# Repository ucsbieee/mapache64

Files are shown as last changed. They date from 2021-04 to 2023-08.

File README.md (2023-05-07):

# Mapache 64

* Repository: [github.com/ucsbieee/mapache64](https://github.com/ucsbieee/mapache64)
* Website: [mapache64.ucsbieee.org](https://mapache64.ucsbieee.org)
* Discord Server: [discord.ucsbieee.org](http://discord.ucsbieee.org)

## Description

Mapache 64 is is a custom video game console based around the 6502 microprocessor. This console uses a custom graphics processing unit (GPU) written in SystemVerilog and runs on a [Cmod A7-35T](https://digilent.com/reference/programmable-logic/cmod-a7/). The firmware and games are programmed using C, and can be compiled with a custom linker script and [`cc65`](https://cc65.github.io), an open-source C to 6502 assembly compiler. This project was developed by [UC Santa Barbara's IEEE chapter](https://ucsbieee.org/), led by [Ethan Sifferman](https://github.com/sifferman).

Video screen:

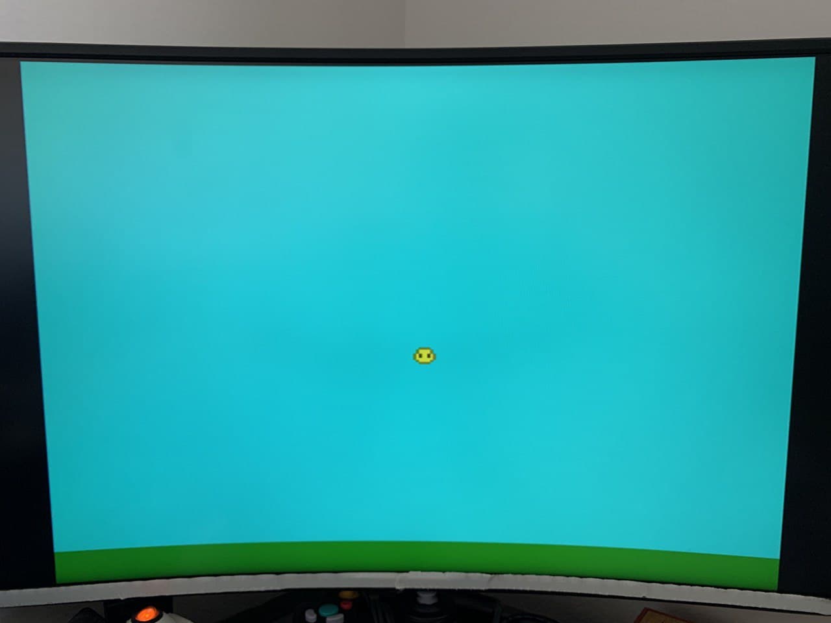
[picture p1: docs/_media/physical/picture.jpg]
Video Screen


Breadboard circuit:

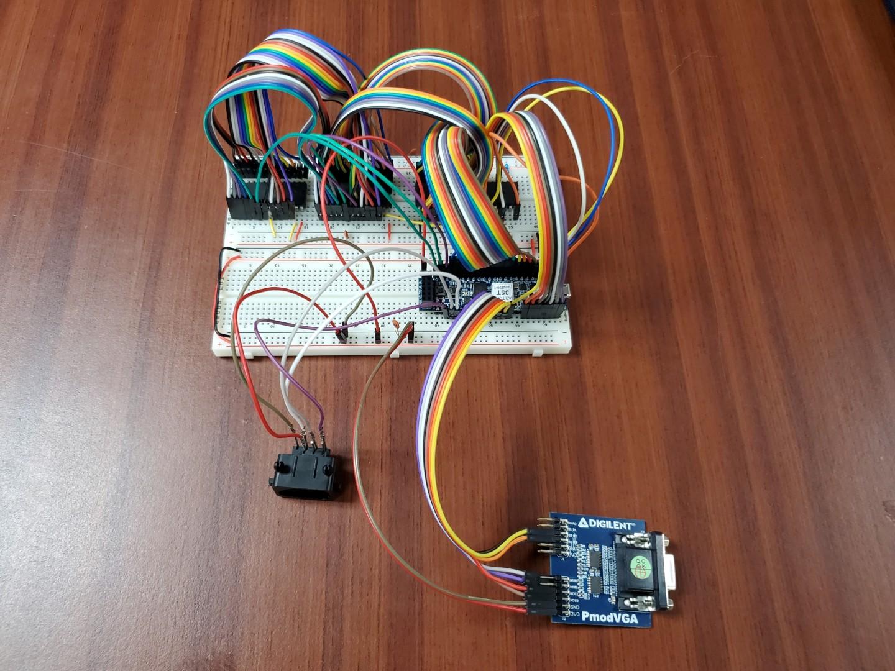
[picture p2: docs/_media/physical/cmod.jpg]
Breadboard Circuit


## References

### Games List

* [Asteroids](https://github.com/sifferman/m64-a2teroids) (2-player asteroids)
* [Flappy Bird](https://github.com/mfletcher2/mapache64-flappybird)
* [Snake](https://github.com/GDW1/m64-snake)
* [Pong](https://github.com/GDW1/m64-pong)
* [Tetris](https://github.com/ucsbieee/m64-tetris)
* [Frogger](https://github.com/ucsbieee/m64-frogger)

### Guides

* [Ben Eater 6502 Computer Video Series](https://www.youtube.com/watch?v=LnzuMJLZRdU&list=PLowKtXNTBypFbtuVMUVXNR0z1mu7dp7eH)
* [Ben Eater VGA](https://youtu.be/uqY3FMuMuRo)
* [NES PPU Explanation](https://www.youtube.com/watch?v=-THeUXqR3zY&list=PLrOv9FMX8xJHqMvSGB_9G9nZZ_4IgteYf&index=5)

### Datasheets

* [W65C02S](https://westerndesigncenter.com/wdc/documentation/w65c02s.pdf) Microprocessor
* [AT28C256](http://ww1.microchip.com/downloads/en/DeviceDoc/doc0006.pdf) 32kB EEPROM
* [AS6C62256](https://www.alliancememory.com/wp-content/uploads/pdf/AS6C62256.pdf) 32kB SRAM
* [Cmod A7](https://digilent.com/reference/programmable-logic/cmod-a7/reference-manual) FPGA board
* [VESA, 640x480 @ 60 Hz Video Timing](http://www.tinyvga.com/vga-timing/640x480@60Hz) guide

---

### Credits

#### RTL Development

* Ethan Sifferman ([github](https://github.com/sifferman))
* *Jon Balkind (consultant)* ([github](https://github.com/jbalkind))

#### PCB Development

* Ethan Sifferman ([github](https://github.com/sifferman))
* Matthew Tom ([github](https://github.com/Matthew-Tom))
* Kogan Sam ([github](https://github.com/02ks))
* Neil Balch ([github](https://github.com/neilbalch))
* *Daniel Van Dalsem (consultant)* ([github](https://github.com/aWZHY0yQH81uOYvH))

#### Firmware Development

* Ethan Sifferman ([github](https://github.com/sifferman))
* Neil Balch ([github](https://github.com/neilbalch))

#### Game Development

* Ethan Sifferman ([github](https://github.com/sifferman))
* Max Fletcher ([github](https://github.com/mfletcher2))
* Guy Wilks ([github](https://github.com/GDW1))

#### Website Development

* Ethan Sifferman ([github](https://github.com/sifferman))
* Neil Balch ([github](https://github.com/neilbalch))
* Max Fletcher ([github](https://github.com/mfletcher2))
* Xingbu Qin ([github](https://github.com/watercannons))
* Nicolas Guglielmin ([github](https://github.com/nicg6645))

---

## Name Explanation

* Mapache is the unofficial mascot of UC Santa Barbara ([source](https://www.change.org/p/the-mascot-we-deserve-change-the-ucsb-mascot-to-a-mapache))
* Mapache 64 has 64kiB of address space

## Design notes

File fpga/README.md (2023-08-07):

<!-- fpga/README.md -->

# FPGA

Repository: <https://github.com/ucsbieee/mapache64/tree/main/fpga/>

## RTL

This is the RTL for Mapache 64. It consists of the following modules:

* Address Bus
  * Sets chip enable signals according to the current cpu address.
* [Controller Interface](https://github.com/sifferman/nes_controller_interface)
  * Reads the controller values. (SIPO)
* Firmware ROM
  * The firmware and 65c02 vectors are stored in BRAM.
* GPU
  * Implementation of this description: [GPU](https://mapache64.ucsbieee.org/guides/gpu/).

## Required tools

* [FuseSoC](https://github.com/olofk/fusesoc)
* [OSS CAD Suite](https://github.com/YosysHQ/oss-cad-suite-build)
* [Vivado ML Enterprise](https://www.xilinx.com/products/design-tools/vivado.html)
* [Cmod A7-35T](https://store.digilentinc.com/cmod-a7-breadboardable-artix-7-fpga-module/)

## Usage

```bash
# setup
git submodule update --init --recursive
cd fpga
./rom/get_firmware.sh
./rom/get_font.sh
fusesoc library add ucsbieee_mapache64_top . --sync-type=local
fusesoc library add nes_controller_interface https://github.com/sifferman/nes_controller_interface --sync-type=git

# Lint with Verilator
fusesoc run --target lint --no-export ucsbieee:mapache64:top
# Simulate with Icarus
fusesoc run --target sim --tool icarus ucsbieee:mapache64:top
# Simulate with Verilator
fusesoc run --target sim --tool verilator ucsbieee:mapache64:top
# Synthesize for the Cmod-A7
fusesoc run --target cmod_a7 ucsbieee:mapache64:top
# Verify the GPU
fusesoc run --target gpu_verify ucsbieee:mapache64:top
```

Cmod-A7 SPI Flash: `mx25l3273f`

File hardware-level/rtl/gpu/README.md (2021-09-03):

<!-- hardware-level/rtl/gpu-reduced/README.md -->

# GPU

Repository: <https://github.com/ucsbieee/arcade/tree/main/hardware-level/rtl/gpu>

## About

This is a draft of the GPU described in [GPU](https://arcade.ucsbieee.org/guides/gpu/).

## Required tools

* [FuseSoC](https://github.com/olofk/fusesoc) ([installation](https://fusesoc.readthedocs.io/en/stable/user/installation.html))
* [Icarus Verilog](http://iverilog.icarus.com/) ([installation](https://iverilog.fandom.com/wiki/Installation_Guide))
* [Vivado ML Enterprise](https://www.xilinx.com/products/design-tools/vivado.html) ([installation](https://www.xilinx.com/support/download.html))
* [Nexys A7-100T](https://store.digilentinc.com/nexys-a7-fpga-trainer-board-recommended-for-ece-curriculum/)
* [CMOD A7-35T](https://store.digilentinc.com/cmod-a7-breadboardable-artix-7-fpga-module/)

## Usage

To simulate in Icarus Verilog:

```bash
./scripts/sim.sh
```

To synthesize for Nexys A7-100T:

```bash
./scripts/nexys_a7.sh
```

To synthesize for CMOD A7-35T:

```bash
./scripts/cmod_a7.sh
```

Libraries Used:

* [E4tHam/find_first_set](https://github.com/E4tHam/find_first_set)

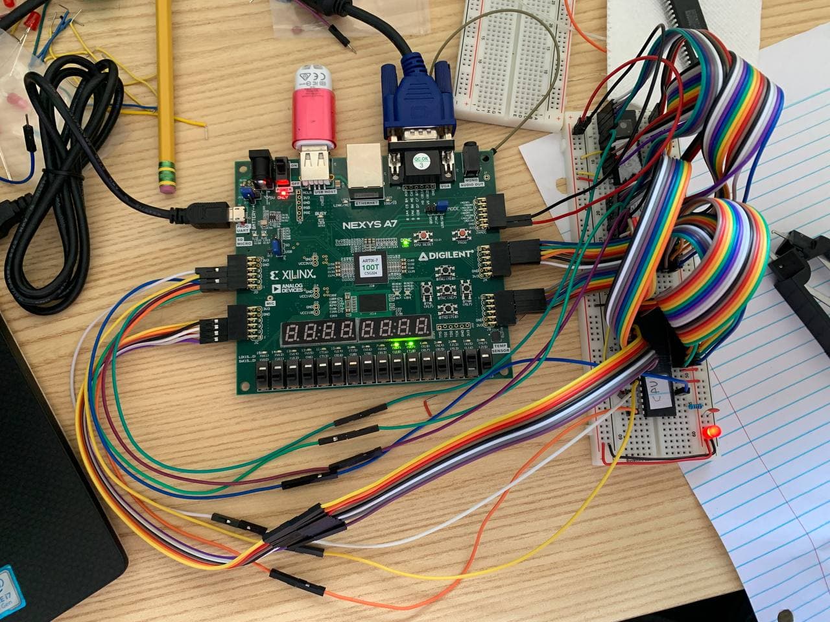
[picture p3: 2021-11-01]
docs/_media/physical/nexys_a7.jpg

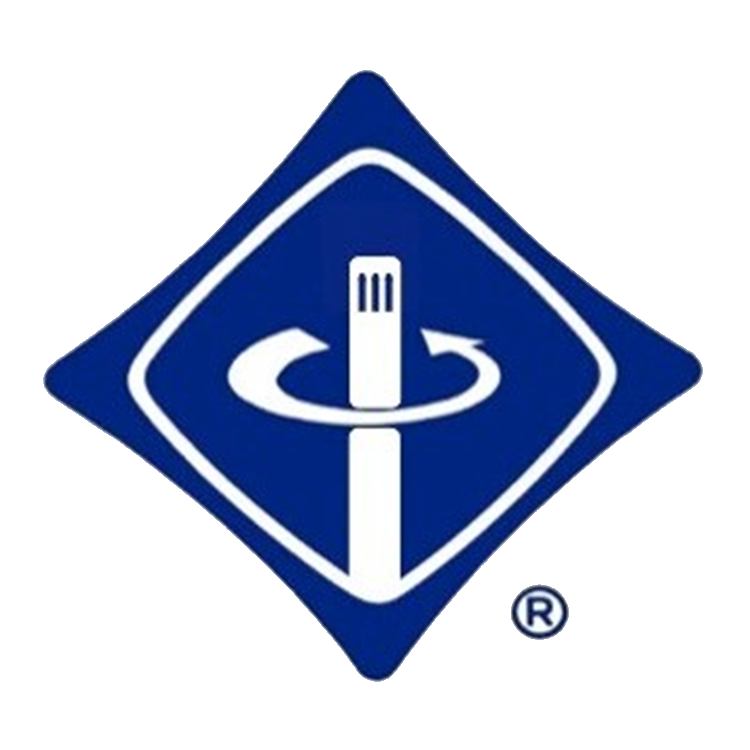
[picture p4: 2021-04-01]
docs/_media/UCSB-IEEE.png

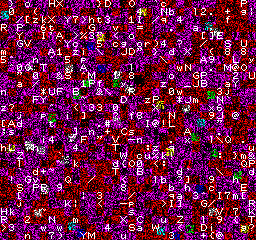
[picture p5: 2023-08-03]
fpga/dv/gpu/gold_images/random_red_magenta.png

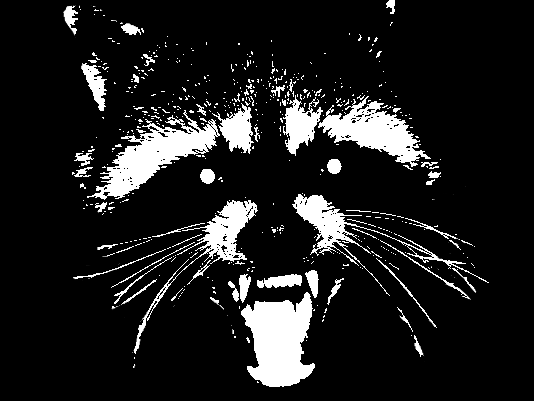
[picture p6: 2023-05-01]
PCB/mapache.png

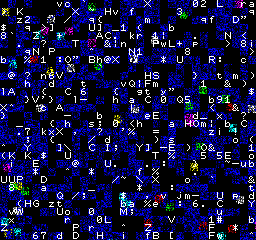
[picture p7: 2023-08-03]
fpga/dv/gpu/gold_images/random_blue_black.png

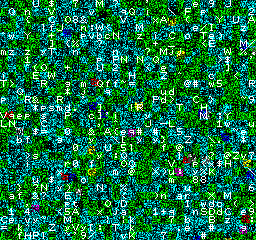
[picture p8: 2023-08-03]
fpga/dv/gpu/gold_images/random_green_cyan.png

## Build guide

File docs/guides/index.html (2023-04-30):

back

# Guides

- GPU Explanation
- Creating a Game (https://github.com/ucsbieee/mapache64/tree/main/firmware#creating-a-game)
- Emulating a Game in JavaScript

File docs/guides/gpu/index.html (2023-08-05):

back

# GPU

# Table of Contents

- Overview
- Pattern Memory
- Nametable
- Object Memory
- Text Table
- Video Timing

# Overview

All the GPU does is display to the screen based off what is in the VRAM. Therefore, to display to the screen, you must fill the VRAM accordingly. If you are using Mapache 64's custom linker script, you can use the API described in vram.h (https://github.com/ucsbieee/mapache64/blob/main/firmware/headers/vram.h).

There are 4 parts of the VRAM: Pattern Memory, Nametable, Object Memory, and Text Table.

- The pattern memory (PMF and PMB) stores pixel data for 32 foreground sprites and 32 background sprites.
- The Nametable (NTBL) stores the arrangement of 32×30 background tiles on the screen.
- The Object Memory (OBM) stores the arrangement of 64 foreground sprites.
- The Text Table (TXBL) stores the arrangement of 32×30 characters on the screen.

If you’ve never worked with sprites and tiles, I recommend learning how NES sprites are stored and assembled into metasprites before proceeding:

Ethan’s Image Binary Data Lecture (https://ieee.sifferman.dev/W21-BinHacking/Lecture/21-01-30/#Sprites)

Note: the GPU in this project took heavy inspiration from the NES’s PPU:

One Lone Coder’s NES PPU Explanation (https://www.youtube.com/watch?v=-THeUXqR3zY&list=PLrOv9FMX8xJHqMvSGB_9G9nZZ_4IgteYf&index=5)

# Pattern Memory

Pattern Memory stores collections of 8px×8px sprites. Each pixel is stored with 2 bits, and a group of 4 pixels is stored as 1 byte. Each sprite is 16 bytes total.

Pixel Data

- 11 is white
- 10 is light gray
- 01 is dark gray
- 00 is transparent for PMF, black for PMB

Note: pixel data is separate from color data. A color filter can be applied over a sprite by the Nametable or Object Memory.

Pixel Data

- Pattern Memory Foreground (PMF) only holds 32 foreground sprites, and is addressable with 5 bits.
- Pattern Memory Background (PMB) only holds 32 background sprites, and is addressable with 5 bits.

Observe the layout of the Pattern Memory:

Pattern Memory Diagram

This is an example of how sprites are stored in PMF.

# Nametable

The Nametable is a 32×30 array of tiles that represent the entire 256px×240px screen. Each tile must choose 1 sprite from PMB to display. Each tile can be flipped horizontally and flipped vertically. This allows for reuse of sprites.

The Nametable also stores 2 global colors. Each tile must select one of the two colors. You can look at the VRAM Randomizer example to see this in action.

Nametable Diagram

# Object Memory

The Object Memory is used to identify the location of the sprites on the screen.

Each object has an X and Y position, a sprite address, an H-Flip and V-Flip modifier, and a color. If two objects overlap, whichever object appears first in OBM will be on top.

Object Memory Diagram

# Text Table

The Text Table (TXBL) can be used to write text over the screen. The TXBL is similar to the NTBL, except the TXBL's tiles appear in front of foreground objects and uses read-only character pattern memory (PMC) instead of custom sprites from the PMB.

There are 128 characters in the font. Each character can be accessed by using the lower 7 bits of the character data in the TXBL. The font uses ASCII for all printable characters.

PMC Font (https://github.com/ucsbieee/mapache64/blob/main/txbl_font/font.png)

If the character data's color select is 0, the character is printed black. If the character data's color select is 1, the character is printed white.

Text Table Diagram

# Video Timing

The GPU will follow the VESA 640×480 @ 60 Hz protocol (http://www.tinyvga.com/vga-timing/640x480@60Hz). Observe this timing diagram:

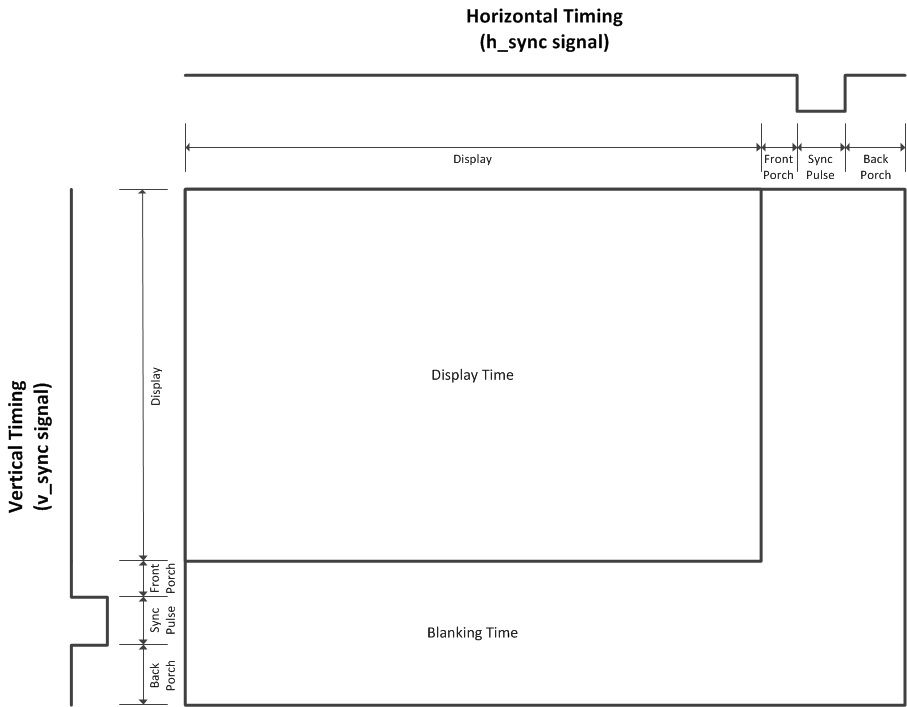
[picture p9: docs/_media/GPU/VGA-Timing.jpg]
VGA Timing Diagram
 (https://www.digikey.com/eewiki/pages/viewpage.action?pageId=15925278)

The GPU updates each pixel row by row. After drawing a row, it waits for a horizontal blanking period. After finishing the entire frame, it waits for a vertical blanking period.

If you want more information about video timings, watch this:

Ben Eater Graphics Card Video (https://youtu.be/l7rce6IQDWs)

## Interrupts

The CPU must only touch the VRAM while inside the fill_vram subroutine. This ensures that the CPU and the GPU are not trying to access the VRAM at the same time. Every time the GPU needs to use the VRAM, it sends an interrupt to the CPU. If the CPU is in fill_vram, it will pause. Once the GPU no longer needs the VRAM, it will send another interrupt to the CPU so that the CPU knows when to continue. Observe this code:

interrupts.s (https://raw.githubusercontent.com/ucsbieee/mapache64/main/firmware/backend_src/crt0.s)

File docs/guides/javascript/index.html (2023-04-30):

back

# JavaScript

# Table of Contents

- Game Code Structure
- Fixed Point
- Running JavaScript

# JavaScript Code Structure

JavaScript can be used to write emulations of games. This may be helpful since the C development tools are more difficult. This guide will help you get started.

## HTML

Your HTML file must include the scripts firmware.js, font.js machine.js, game.js, and player.js in that order; and it must include div#Game in body. Example code: game-demo/index.html (https://github.com/ucsbieee/mapache64/blob/main/docs/examples/game-demo/index.html).

## JavaScript

Your JavaScript file must have the functions reset(), do_logic(), and fill_vram(). Example code: game-demo.js (https://github.com/ucsbieee/mapache64/blob/main/docs/_emulator/examples/game-demo.js).

- reset(): run once at the beginning of the code
- do_logic(): run 60 times a second. Put as much game logic here as you can. However, do not touch the VRAM
- fill_vram(): run after do_logic(), once in the vertical blanking area. Here, you can touch the VRAM

# Floating Point vs. Fixed Point

The 65C02 does not have any built-in floating-point functionality. Therefore, we will instead use fixed-point numbers for continuous values.

Fixed Point Numbers (https://en.wikipedia.org/wiki/Q_(number_format))

We have a Q9_6 implementation in firmware.js (https://github.com/ucsbieee/mapache64/blob/main/docs/_emulator/firmware.js). You can see its usage in game-demo.js (https://github.com/ucsbieee/mapache64/blob/main/docs/_emulator/examples/game-demo.js).

Never use floating point numbers! If you need non-integers, use Q9_6.

# Running JavaScript

JavaScript is run by opening an html file in a browser. The easiest way to open html files is through VSCode and Live Server. Install it here:

Live Server VS Code (https://marketplace.visualstudio.com/items?itemName=ritwickdey.LiveServer)

To include a JavaScript file in an html file, you need to add a script:src tag to the head section, and provide the source path/link. Observe this code block:

Note: Append defer to all script elements.

## CDNs

CDN stands for content delivery network. We use a CDN to retrieve JavaScript files from https links instead of paths. A JS Deliver (https://www.jsdelivr.com/github) CDN link has this structure: https://cdn.jsdelivr.net/gh/<org/user name>/<repository>@main/<path>. Any changes to files that are pointed to by a CDN link will take ~2 hours to show up.

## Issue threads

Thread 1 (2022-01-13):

New Functionality: FPS Limiter

E4tHam, 2022-01-13:
There should be support for FPS limiting by integer division (60, 30, 20, 15, 12...).

## Proposed Solution

1. Add a clock to the FPGA that outputs "time since reset" to a 4 byte register in ($7000...$7fff).
2. In [crt0.s](https://github.com/ucsbieee/mapache64/blob/edd41f/assembly-level/src/backend_src/crt0.s), instead of immediately jumping into the interrupt handler on [L82](https://github.com/ucsbieee/mapache64/blob/edd41f/assembly-level/src/backend_src/crt0.s#L82), there should be a check for if enough time has passed.

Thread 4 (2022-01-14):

New Functionality: Firmware Error Code

E4tHam, 2022-01-14:
Currently, if the fpga firmware header does not match the rom firmware header, the M64 will print `'F'` in `TXBL[0][0]`. This is implemented in [`handle_bad_firmware`](https://github.com/ucsbieee/mapache64/blob/e23d07/assembly-level/src/backend_src/verify_firmware.s#L41-L47). Ideally, there should be a more detailed error code.

## Proposed Solution

If the firmwares don't match, we should print both the fpga firmware header and rom firmware header. Note that if the null terminator is not found in a header, the header is assumed to be 256 bytes.

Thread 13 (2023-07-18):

Documentation: Pattern Memory Diagram Should be fixed

sifferman, 2023-07-18:
The provided diagram that demonstrates pattern memory should be corrected. Currently, a diagram representing what the NES does is provided:
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

A better image to use would probably be to use the picture from the "game demo": https://github.com/ucsbieee/mapache64/blob/3403696af758ce0635e767c9e549b5889565007a/firmware/demos/game/patterns.c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

sifferman, 2023-08-04:
Fixed by ed003a65cb620b7cf53a0c9cba3a19346fb04f44

Closed 2023-08-04.

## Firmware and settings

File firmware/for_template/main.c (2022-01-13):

// ==================== main.c ==================== //
// Follow this file template to implement your game //
// ================================================ //

#define SIM 1 // change value depending if running simulation or not

// ================================ //
#pragma code-name ("CODE")
#pragma bss-name ("BSS")

#include <int.h>
#include <vram.h>
#include <stop.h>
#include <Q9_6.h>
#include <mapache64_zero_page.h>
#include <controller.h>
#include <screen.h>


// run once on startup
void reset(void) { }

// run 60 times a second
void do_logic(void) { }

// run after do_logic and once gpu is idle
void fill_vram(void) { }

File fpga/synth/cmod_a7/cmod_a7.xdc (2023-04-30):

## This file is a general .xdc for the CmodA7 rev. B
## https://github.com/Digilent/digilent-xdc/blob/master/Cmod-A7-Master.xdc
## To use it in a project:
## - uncomment the lines corresponding to used pins
## - rename the used ports (in each line, after get_ports) according to the top level signal names in the project

## 12 MHz Clock Signal
set_property -dict { PACKAGE_PIN L17   IOSTANDARD LVCMOS33 } [get_ports { sysclk }]; #IO_L12P_T1_MRCC_14 Sch=gclk

## LEDs
set_property -dict { PACKAGE_PIN A17   IOSTANDARD LVCMOS33 } [get_ports { led[0] }]; #IO_L12N_T1_MRCC_16 Sch=led[1]
set_property -dict { PACKAGE_PIN C16   IOSTANDARD LVCMOS33 } [get_ports { led[1] }]; #IO_L13P_T2_MRCC_16 Sch=led[2]

## RGB LED
set_property -dict { PACKAGE_PIN C17   IOSTANDARD LVCMOS33 } [get_ports { led_rgbB[2] }]; #IO_L14P_T2_SRCC_16 Sch=led0_r
set_property -dict { PACKAGE_PIN B16   IOSTANDARD LVCMOS33 } [get_ports { led_rgbB[1] }]; #IO_L13N_T2_MRCC_16 Sch=led0_g
set_property -dict { PACKAGE_PIN B17   IOSTANDARD LVCMOS33 } [get_ports { led_rgbB[0] }]; #IO_L14N_T2_SRCC_16 Sch=led0_b

## Buttons
set_property -dict { PACKAGE_PIN A18   IOSTANDARD LVCMOS33 } [get_ports { btn[0] }]; #IO_L19N_T3_VREF_16 Sch=btn[0]
set_property -dict { PACKAGE_PIN B18   IOSTANDARD LVCMOS33 } [get_ports { btn[1] }]; #IO_L19P_T3_16 Sch=btn[1]

## Pmod Header JA
#set_property -dict { PACKAGE_PIN G17   IOSTANDARD LVCMOS33 } [get_ports { ja[0] }]; #IO_L5N_T0_D07_14 Sch=ja[1]
#set_property -dict { PACKAGE_PIN G19   IOSTANDARD LVCMOS33 } [get_ports { ja[1] }]; #IO_L4N_T0_D05_14 Sch=ja[2]
#set_property -dict { PACKAGE_PIN N18   IOSTANDARD LVCMOS33 } [get_ports { ja[2] }]; #IO_L9P_T1_DQS_14 Sch=ja[3]
#set_property -dict { PACKAGE_PIN L18   IOSTANDARD LVCMOS33 } [get_ports { ja[3] }]; #IO_L8P_T1_D11_14 Sch=ja[4]
#set_property -dict { PACKAGE_PIN H17   IOSTANDARD LVCMOS33 } [get_ports { ja[4] }]; #IO_L5P_T0_D06_14 Sch=ja[7]
#set_property -dict { PACKAGE_PIN H19   IOSTANDARD LVCMOS33 } [get_ports { ja[5] }]; #IO_L4P_T0_D04_14 Sch=ja[8]
#set_property -dict { PACKAGE_PIN J19   IOSTANDARD LVCMOS33 } [get_ports { ja[6] }]; #IO_L6N_T0_D08_VREF_14 Sch=ja[9]
#set_property -dict { PACKAGE_PIN K18   IOSTANDARD LVCMOS33 } [get_ports { ja[7] }]; #IO_L8N_T1_D12_14 Sch=ja[10]

## Analog XADC Pins
## Only declare these if you want to use pins 15 and 16 as single ended analog inputs. pin 15 -> vaux4, pin16 -> vaux12
#set_property -dict { PACKAGE_PIN G2    IOSTANDARD LVCMOS33 } [get_ports { xa_n[0] }]; #IO_L1N_T0_AD4N_35 Sch=ain_n[15]
#set_property -dict { PACKAGE_PIN G3    IOSTANDARD LVCMOS33 } [get_ports { xa_p[0] }]; #IO_L1P_T0_AD4P_35 Sch=ain_p[15]
#set_property -dict { PACKAGE_PIN J2    IOSTANDARD LVCMOS33 } [get_ports { xa_n[1] }]; #IO_L2N_T0_AD12N_35 Sch=ain_n[16]
#set_property -dict { PACKAGE_PIN H2    IOSTANDARD LVCMOS33 } [get_ports { xa_p[1] }]; #IO_L2P_T0_AD12P_35 Sch=ain_p[16]
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

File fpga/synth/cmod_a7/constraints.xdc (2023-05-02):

# Artix-7
set_property CONFIG_VOLTAGE 3.3 [current_design]
set_property CFGBVS VCCO [current_design]

# Bitstream
set_property BITSTREAM.GENERAL.COMPRESS TRUE [current_design]
set_property BITSTREAM.CONFIG.CONFIGRATE 33 [current_design]
set_property CONFIG_MODE SPIx4 [current_design]

# CPU Clock Signal
create_generated_clock -name cpu_clk -source [get_pins cpu_clk_divider/clk_i] -divide_by 2 [get_pins cpu_clk_divider/clk_o]
set_false_path -from [get_clocks clk_12_5875_clk_mmcm] -to [get_clocks cpu_clk]

# Controller Clock Signal
create_generated_clock -name controller_clk -source [get_pins controller_clk_divider/clk_i] -divide_by 16 [get_pins controller_clk_divider/clk_o]
set_false_path -from [get_clocks clk_12_5875_clk_mmcm] -to [get_clocks controller_clk]

# VGA Speed
set_output_delay -clock clk_12_5875_clk_mmcm -max 2.0 [get_ports {pio28 pio27 pio30 pio29 pio32 pio31 pio33 pio34}]

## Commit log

2021-03-27 es - switched to PixelBuffer and putImageData to improve rendering performance
2021-03-28 es - moved frame and FPS to machine.js
2021-04-02 es - added assembly guide
2021-04-03 es - added more assembly guides
2021-04-09 es - add running assembly documentation
2021-04-09 es - added references to assembly tools
2021-04-09 es - fixed add8
    [add.asm]
2021-04-20 es - ignore assembly option files
2021-04-23 es - added interrupt test
2021-04-24 es - added interrupt handling to firmware
2021-04-26 es - added FRAME label and increment macro
2021-04-29 es - updated javascript interrupts to match assembly
2021-04-29 es - updated assembly dependency updater
2021-04-30 es - added reset on _reset and increment frame correctly
2021-05-02 es - reverted frame rate to 60fps
2021-05-02 es - added boiler for pattern-gen assembly
2021-05-14 es - wait is now called before enabling interrupts
2021-05-15 es - switched shell scripts to use LF
2021-07-25 [gpu] incorporated fusesoc
2021-07-26 Revert "[gpu] synthesisable"
    This reverts commit 7bbeb13dec15edd45b1e655fd97e22542d67de85.
    [top.tb.v]
2021-07-27 [gpu] fusesoc+vivado works
2021-07-28 [gpu] fixed latch, added TEST/SIM directives
    [top.tb.v]
2021-07-30 [gpu] added ffs fusesoc module
2021-07-30 [gpu tools] added fusesoc scripts
2021-07-31 [gpu tools] added `.fusesoc_path` and `verify.sh`
2021-08-11 [fpga] added cmod_a7 board to top
2021-08-13 [fpga top] fixed inout error
    [top.tb.v]
2021-08-15 [fpga] made cmod_a7 more similar to nexys_a7 (io still doesn't work)
    [cmod_a7.xdc]
2021-08-16 [assembly] fixed `reset`, `do_logic`, and `fill_vram` addresses
    [add.asm]
2021-08-16 [assembly] rewrote zero page with `.byte`s
2021-08-16 [assembly firmware] added `wai` to `vblank_irq` handler
2021-08-16 [assembly firmware] fixed typos
2021-08-18 [fpga] fixed linter include errors
    [top.tb.v]
2021-09-05 [controller] added timer to latch
2021-09-05 [controller] swapped if/else for case
2021-09-05 [assembly] changed controller input method
2021-09-07 [fpga] tested vectors (still broken)
    [top.tb.v]
2021-09-09 [controller] fixed controller reading bug
    [top.tb.v]
2021-09-25 [assembly] updated game template
2021-09-29 [assembly] added listing to dump
2021-09-30 [assembly] fixed listing
2021-09-30 [assembly] renamed `misc_Q9_6.asm` to `Q9_6.asm`
2021-10-01 [assembly] added cmp macros
2021-10-06 [doc] improved interrupt explanation
2021-10-06 [assembly] simplified draw test
2021-10-06 [cmod-a7] buttons and leds enabled
2021-10-09 [assembly] added file full of `nop`s for testing
2021-10-09 [assembly] fixed tests/draw.asm description
2021-10-10 [assembly tools] update p65mon to latest version
2021-12-02 added cc65 setup and moved old assembly code to `assembly-level/old`
    [arcade.cfg]
2021-12-15 fixed typos and organization
    [top.tb.v]
2021-12-18 [docs] fixed typos after switching to C
2021-12-18 [assembly] cc65 optimization flags, cycle count, and make run is default
2021-12-22 [documentation] improved assembly README and Makefile
2022-01-04 [assembly] typos
2022-01-04 vram exists in 4000-4fff
    [arcade.cfg]
2022-01-04 [firmware] firmware is now stored in firmware/fusesoc/rom
2022-01-10 Renamed "Arcade" to "Mapache 64"
    [mapache64.cfg]
2023-04-22 reorganized RTL; sim works, synth broken
    [cmod_a7.xdc, top.tb.v]
2023-04-30 switch to controller fusesoc library
2023-04-30 deleted unused files, reorganized remaining files
    [mapache64.cfg]
2023-05-01 PCB gerber files as ordered
    [Drill_NPTH_Through.DRL, Drill_PTH_Through.DRL, Drill_PTH_Through_Via.DRL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]
2023-05-02 synth for PCB
2023-08-03 added dump vram button to gpu-showcase
2026-03-03 Add logic to support write-only devices on the expansion port
